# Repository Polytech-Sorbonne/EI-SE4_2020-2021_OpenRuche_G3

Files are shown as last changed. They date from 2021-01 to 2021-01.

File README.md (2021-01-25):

# Projet Open Ruche 2020-2021

Ce projet avait pour but de concevoir une ruche connectée afin de vérifier la production de miel des abeilles ainsi que leur bonne santé. Il a été conduit de     
septembre 2020 jusque janvier 2021 par quatre élèves de Polytech Sorbonne EISE4 : Clément Leboulenger, Edouard Matheu, Julie Rago et Clément Roger.

Notre ruche connectée comportait un PCB utilisant un microcontrôleur L432KC et implémentait différents capteurs et fonctionnalités:

  - Un capteur mesurant la température et l'humidité extérieures (le DHT22)
  - Un capteur mesurant la température intérieure (le DS18B20)
  - Une station météo mesurant la vitesse du vent (la LEXCA007)
  - Un capteur de poids (le HX711)
  - Un boitier étanche et facile d'utilisation comportant un bouton ON / OFF et une LED
  - Une mesure du pourcentage de la batterie
  - Une transmission des données sur une plateforme de visualisation des données (Ubidots)
  - Une application d'alertes envoyant des mails au client en cas de problème
 
Tous les codes sources ont été écrits sur mbed et sont disponibles dans le dossier [src](src) 

## Etape 1 : Prototype sur LABDEC

Afin de reproduire le prototype sur labdec il suffit de reproduire le branchement suivant puis de charger le code sur le microcontrôleur avec MBED.

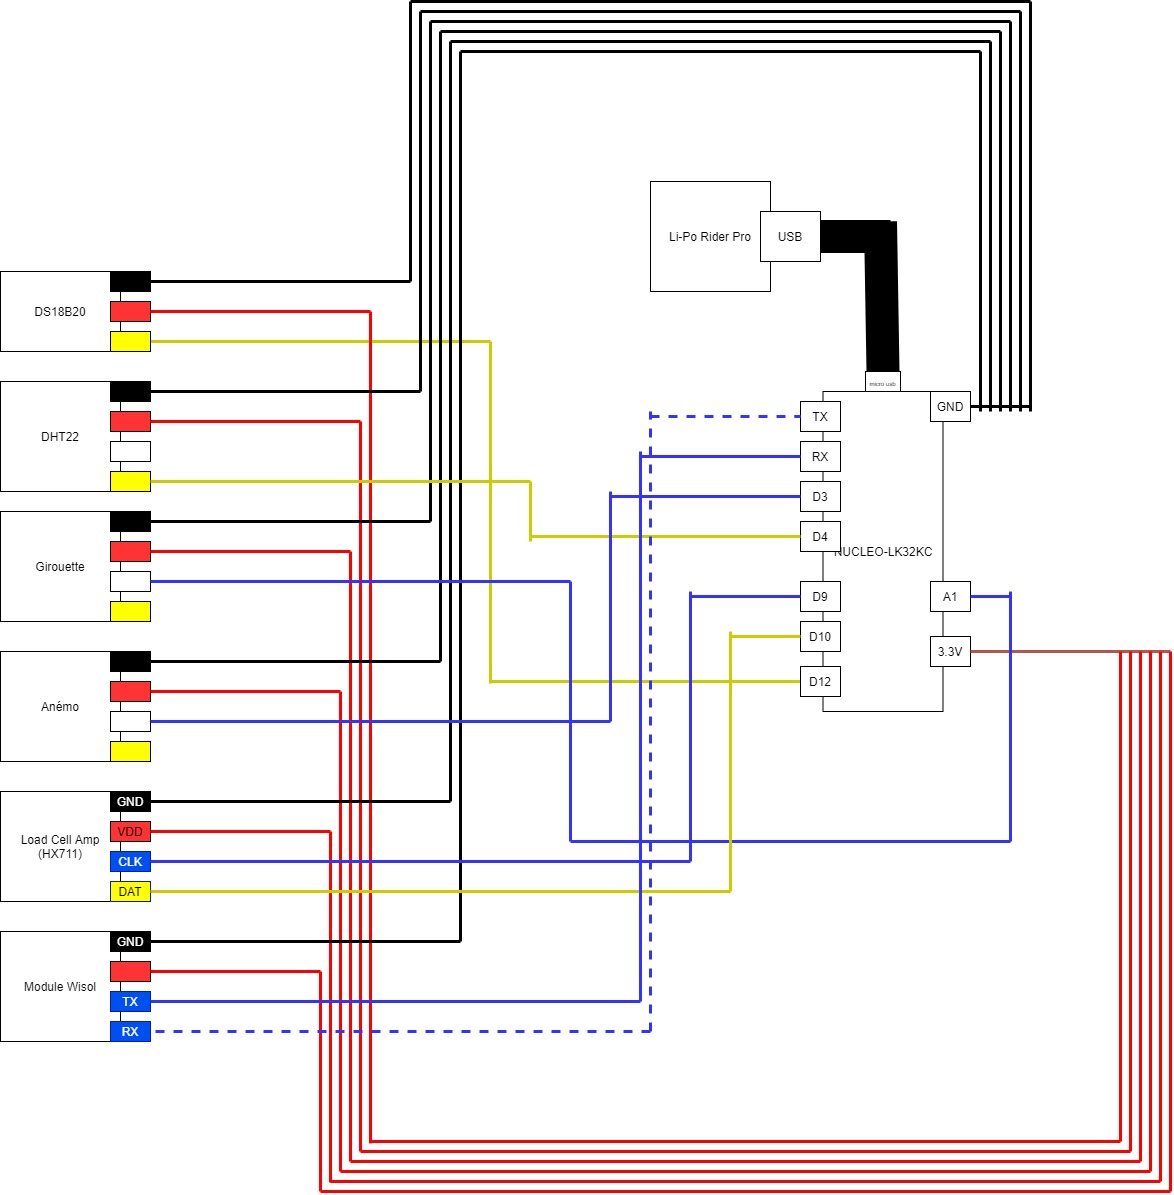
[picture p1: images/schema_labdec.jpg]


## Etape 2 : Visualisation des données

Afin de vérifier le bon fonctionnement du prototype il faut pouvoir visualiser les données reçues. Une première solution est d'afficher ces dernières en série sur le terminal, néanmoins ceci n'est pas viable à long terme.

Nous avons utilisé la plateforme Ubidots qui permet une grande diversité de widgets. Pour cela il faut d'abord programmer le callback. Pour cela, nous vous invitons à suivre ce [tutoriel](https://www.google.com/url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).

Ensuite il suffira de programmer le callback comme suivant :

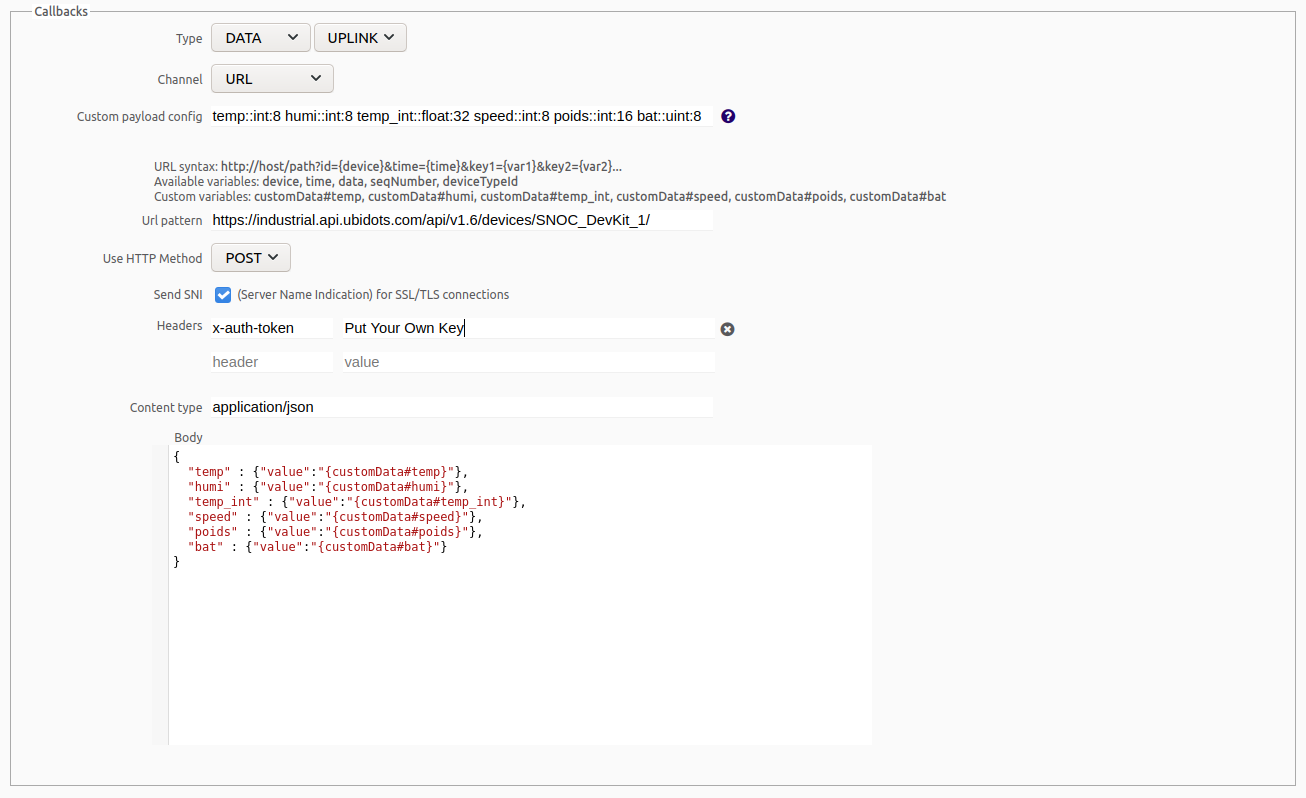
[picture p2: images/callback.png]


## Etape 3 : Création du PCB

Afin d'obtenir un produit final robuste et résistant il convient de concevoir un PCB (ou circuit imprimé).

Le nôtre a été réalisé sur Kicad, tous les fichiers de conception étant présents [ici](kicad_pcb)

## Etape 4 : Branchements sur PCB

Il vous faut maintenant souder les composants (connecteurs Grove, headers ...) et brancher les différents capteurs sur le PCB comme suit :

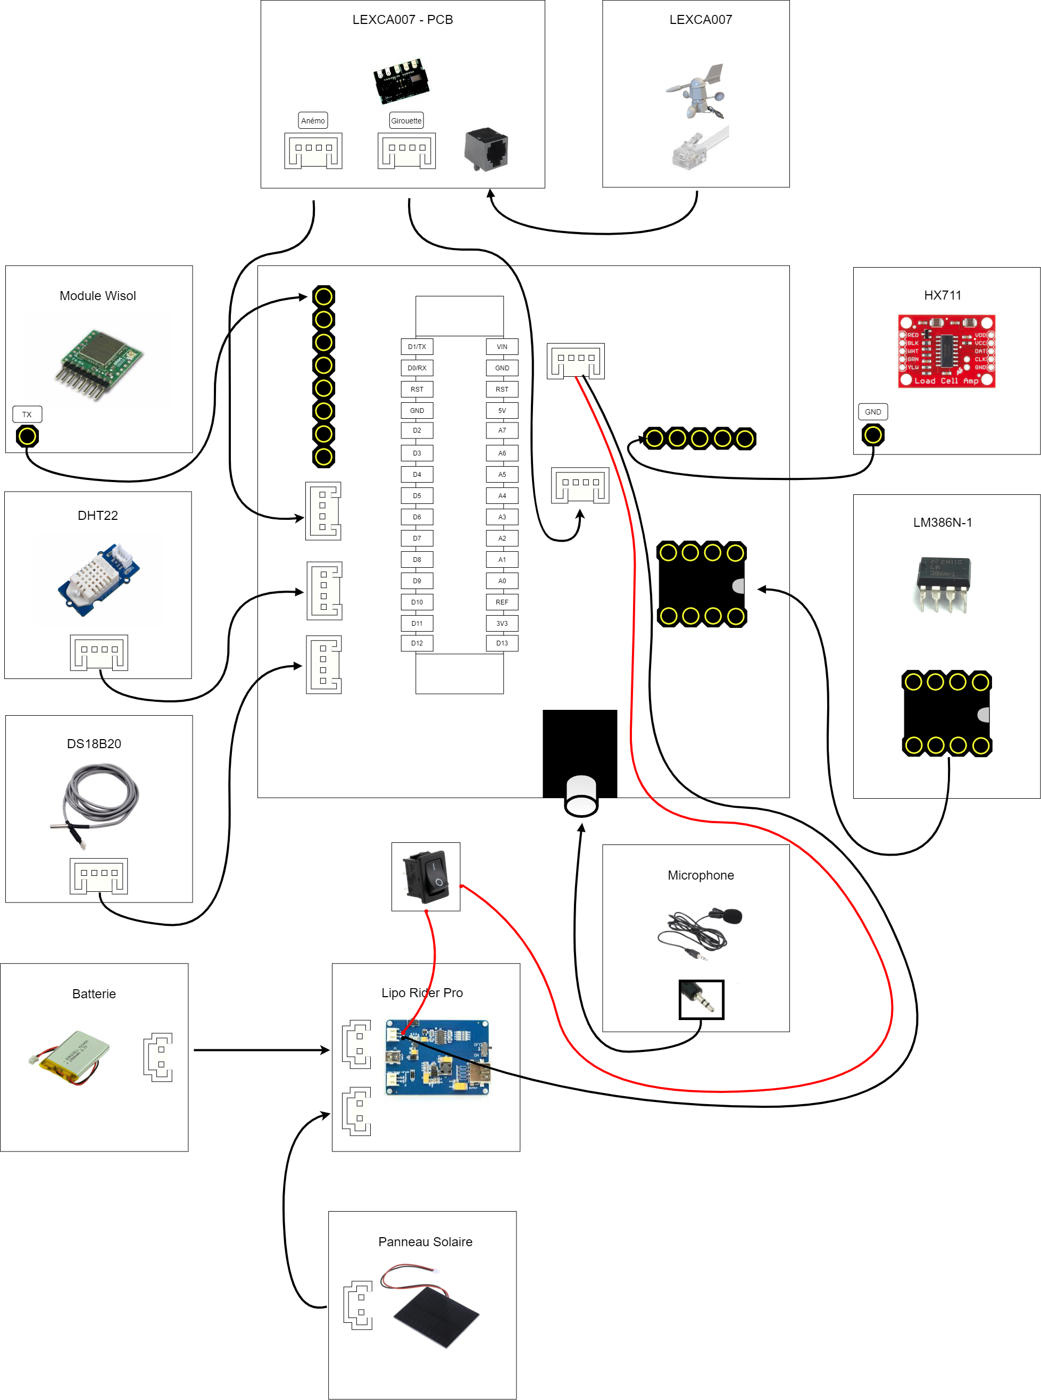
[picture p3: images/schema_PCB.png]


**Après** avoir chargé le code sur le microcontrôleur (car une fois fait vous ne pourrez plus charger de code dessus) il vous faudra néanmoins déssouder des solder bridges sur le microcontrôleur afin de réduire la consommation du système et permettre l'accès du microcontrôleur à certaines pins. 

Les solder bridges à retirer sont les suivants :

  - SB9
  - SB14
  - SB16
  - SB18
  
Les solder bridges sont inscrits directement sur le microcontrôleur ou vous pouvez trouver l'emplacement de ces derniers sur l'image suivante

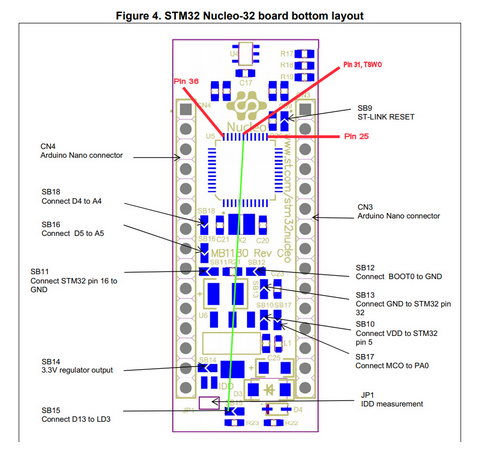
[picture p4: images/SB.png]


Après avoir suivi ces étapes, il ne vous reste plus qu'à mettre le tout dans une boîte étanche.

Vous pouvez également allonger les câbles avec des gaines, isoler le tout avec de la colle à chaud et faire des plateformes pour certains capteurs pour qu'ils tiennent mieux sur la ruche.

Pour tout détail sur l'utilisation, veuillez vous référer à la [notice d'utilisation](documentation_technique/Notice.pdf)

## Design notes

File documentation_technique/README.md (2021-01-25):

# Documentation technique

[stm32l432kc.pdf](stm32l432kc.pdf) contient le datasheet de la nucleo L432KC.

[dm00231744-stm32-nucleo32-boards-mb1180-stmicroelectronics.pdf](dm00231744-stm32-nucleo32-boards-mb1180-stmicroelectronics.pdf) contient le user manual de la nucleo, notamment un schéma électronique de la carte, la position des solder bridges et leur utilité.

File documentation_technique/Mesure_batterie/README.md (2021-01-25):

# Mesure de la batterie

Il convient de savoir que la courbe de la décharge d'une batterie n'est pas linéaire mais a plutôt cette forme (trouvable sur la [datasheet](datasheet.pdf) )

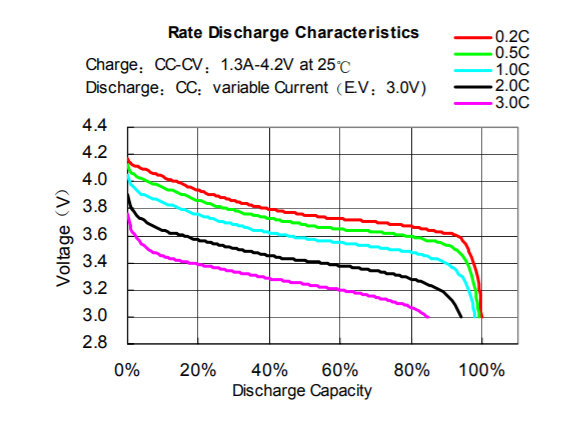
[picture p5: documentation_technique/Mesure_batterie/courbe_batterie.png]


Il est possible d'obtenir la tension d'entrée grâce au micronctôleur en multipliant le résultat de la fonction _read()_ par la tension d'alimentation du microcontrôleur (ici _3.3 V_) et en divisant par 0.6 dû au pont diviseur de tension. Il ne nous reste plus qu'à trouver l'équation de la courbe en fonction de la tension d'entrée afin de pouvoir obtenir la mesure du pourcentage de la batterie.

Pour cela, nous traçons tout d'abord sur Excel la courbe de décharge de la batterie en inversant les axes, le fichier étant disponible [ici](courbe_charge.xlsx). Nous aurons donc le pourcentage de la batterie en fonction de la tension d'entrée comme sur l'image ci dessous.

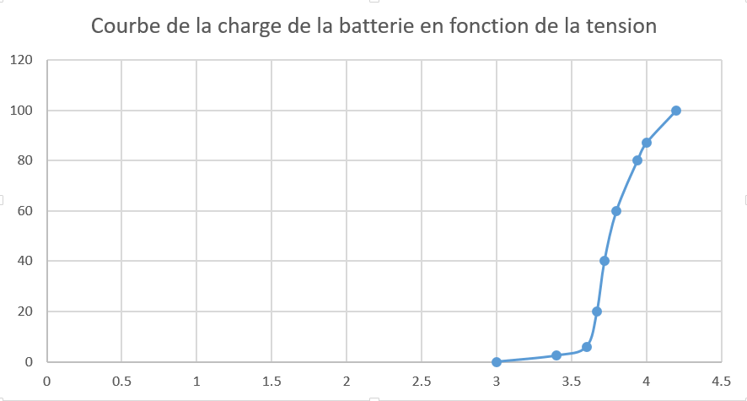
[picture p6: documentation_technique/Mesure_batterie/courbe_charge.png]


Il ne nous reste plus qu'à faire un clique droit sur la courbe et ajouter une courbe de tendance. Excel propose de nombreuses possibilités de modélisations de courbes de tendances (linéaires, polynomiales, logarithmiques ...). Il convient de les tester une à une jusqu'à obtenir celle se confondant le plus possible avec la courbe voulue, puis d'afficher son équation.

La courbe que nous avons étant particulière, nous la divisons en trois tronçons : un tronçon linéaire entre 4 V et 4.2 puis deux tronçons polynomiaux entre 3.6 V et 4 V puis 3 V et 3.6 V. Excel nous fournit donc les équations suivantes qui seront implémentées dans le code.



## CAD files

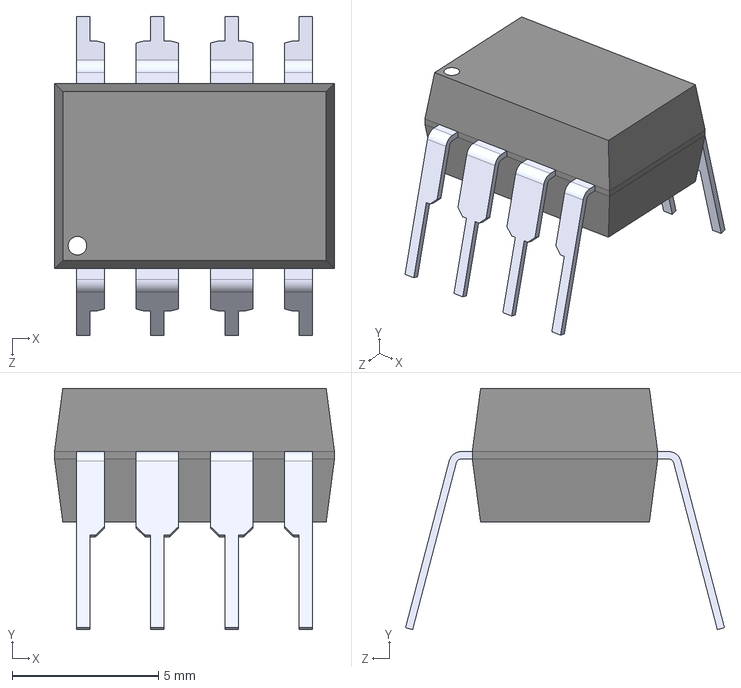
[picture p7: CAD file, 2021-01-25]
kicad_pcb/librairie/LM386N-4_NOPB/LM386N-4_NOPB.step
9.59 x 8.25 x 10.9 mm

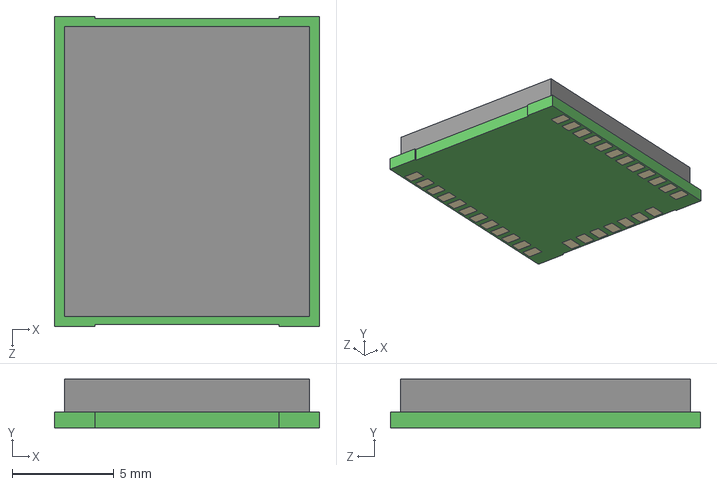
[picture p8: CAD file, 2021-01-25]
kicad_pcb/librairie/WSSFM10R1AT/WSSFM10R1AT.step
13.0 x 2.38 x 15.2 mm

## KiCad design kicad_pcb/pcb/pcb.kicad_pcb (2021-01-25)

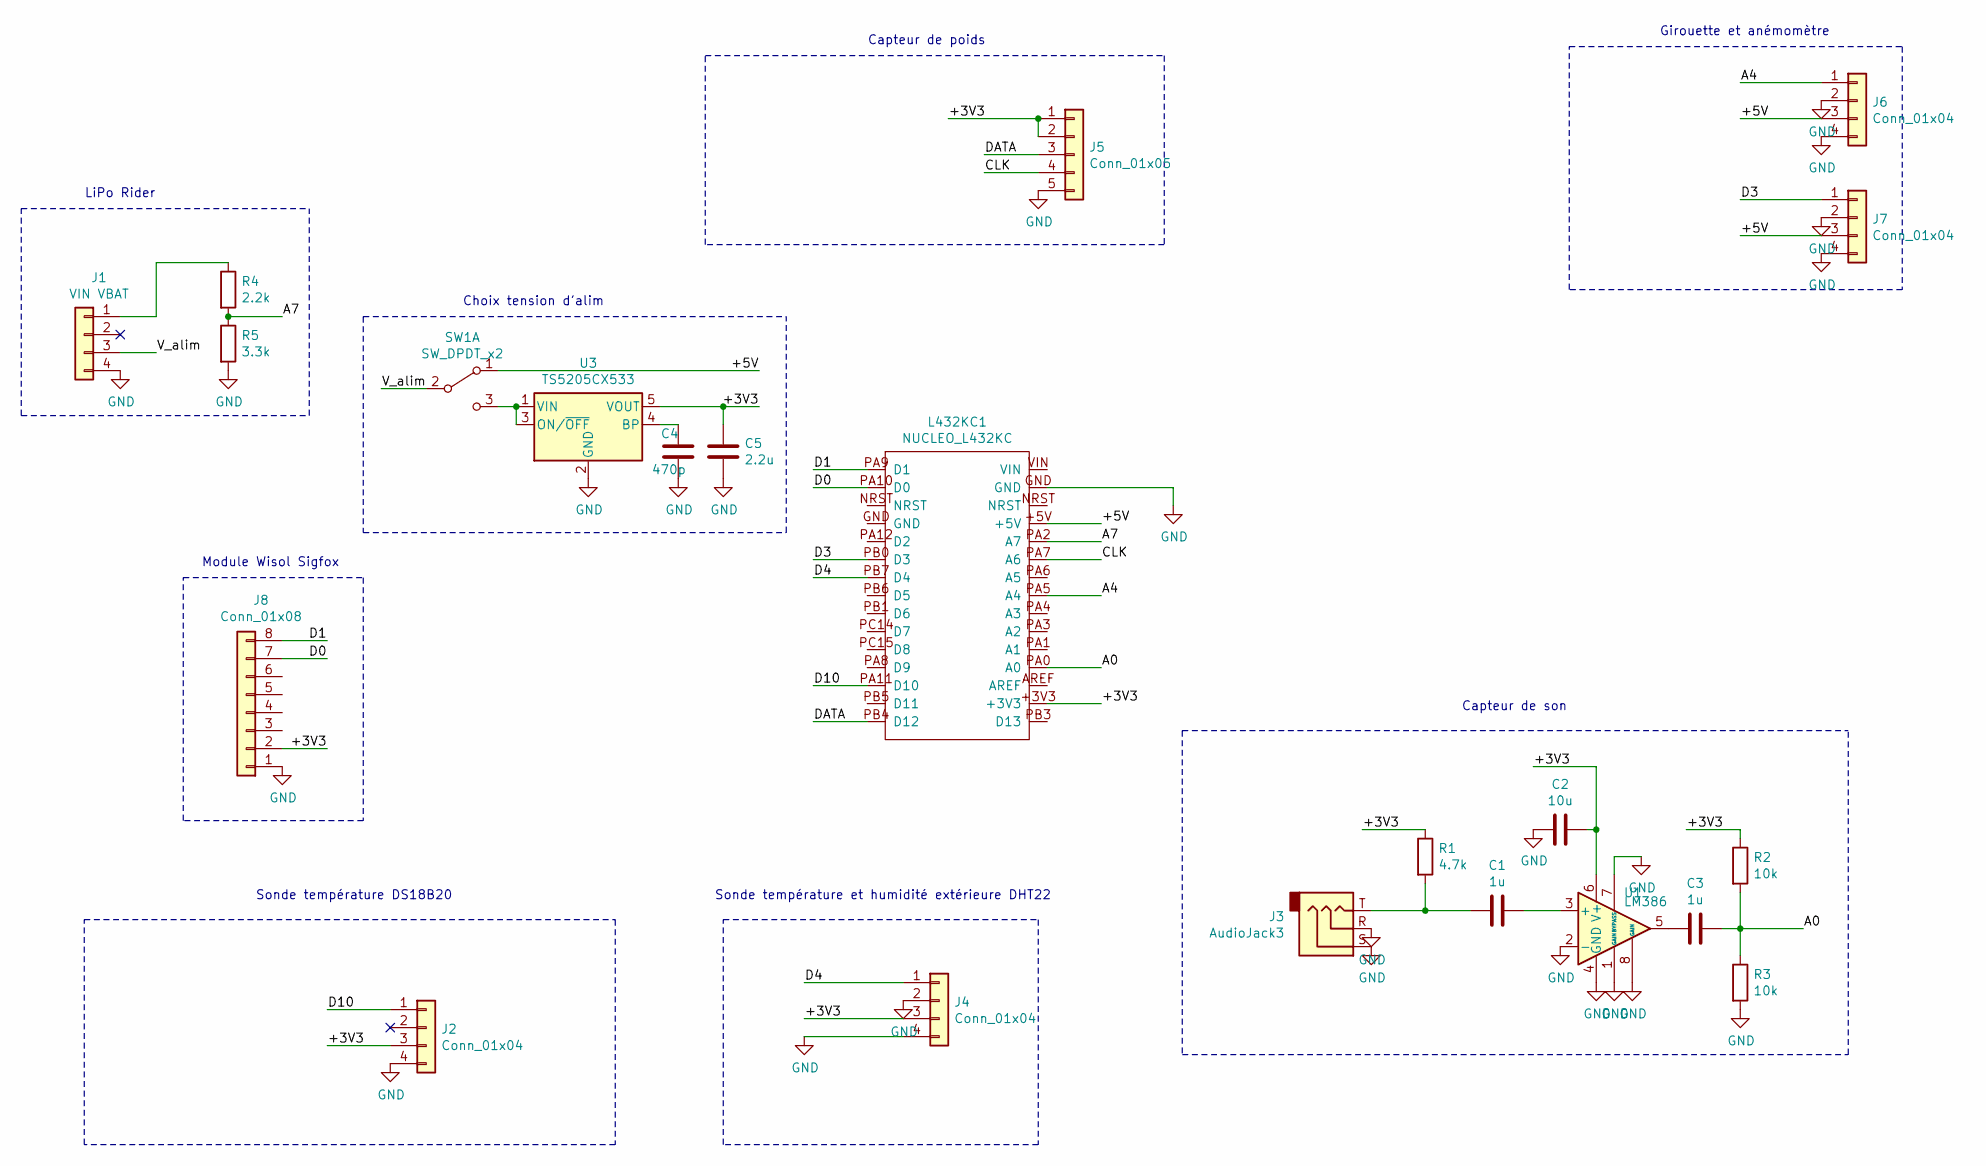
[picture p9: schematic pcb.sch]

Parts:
C1, C3: 1u; CP_Radial_D6.3mm_P2.50mm
C2: 10u; CP_Radial_D5.0mm_P2.00mm
C4: 470p; C_0805_2012Metric_Pad1.18x1.45mm_HandSolder
C5: 2.2u; C_0805_2012Metric_Pad1.18x1.45mm_HandSolder
J1: VIN VBAT; PinHeader_1x04_P2.00mm_Vertical
J2, J4, J6, J7: Conn_01x04; PinHeader_1x04_P2.00mm_Vertical
J3: AudioJack3; Jack_3.5mm_Ledino_KB3SPRS_Horizontal
J5: Conn_01x05; PinHeader_1x05_P2.54mm_Vertical
J8: Conn_01x08; PinHeader_1x08_P2.54mm_Vertical
L432KC1: NUCLEO_L432KC; MODULE_NUCLEO-L432KC
R1: 4.7k; R_Axial_DIN0207_L6.3mm_D2.5mm_P10.16mm_Horizontal
R2, R3: 10k; R_Axial_DIN0207_L6.3mm_D2.5mm_P10.16mm_Horizontal
R4: 2.2k; R_Axial_DIN0207_L6.3mm_D2.5mm_P10.16mm_Horizontal
R5: 3.3k; R_Axial_DIN0207_L6.3mm_D2.5mm_P10.16mm_Horizontal
SW1: SW_DPDT_x2; PinHeader_2x02_P2.54mm_Vertical
U1: LM386; DIP794W45P254L959H508Q8
U3: TS5205CX533; SOT-23-5

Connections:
/+3V3: C2.1, C5.1, J2.3, J4.3, J5.1, J5.2, J8.2, L432KC1.+3V3, R1.1, R2.1, U1.6 (V+), U3.5 (VOUT)
/+5V: J6.3, J7.3, L432KC1.+5V, SW1.1 (A)
/A0: C3.1, L432KC1.PA0 (A0), R2.2, R3.1
/A4: J6.1, L432KC1.PA5 (A4)
/A7: L432KC1.PA2 (A7), R4.2, R5.1
/CLK: J5.4, L432KC1.PA7 (A6)
/D0: J8.7, L432KC1.PA10 (D0)
/D1: J8.8, L432KC1.PA9 (D1)
/D3: J7.1, L432KC1.PB0 (D3)
/D4: J4.1, L432KC1.PB7 (D4)
/D10: J2.1, L432KC1.PA11 (D10)
/DATA: J5.3, L432KC1.PB4 (D12)
/V_alim: J1.3, SW1.2 (B)
GND: C2.2, C4.2, C5.2, J1.4, J2.4, J3.R, J3.S, J4.2, J4.4, J5.5, J6.2, J6.4, J7.2, J7.4, J8.1, L432KC1.GND, R3.2, R5.2, U1.1 (GAIN), U1.2 (-), U1.4 (GND), U1.7 (BYPASS), U1.8 (GAIN), U3.2 (GND)
unnamed: C1.1, U1.3 (+)
unnamed: C1.2, J3.T, R1.2
unnamed: C3.2, U1.5
unnamed: C4.1, U3.4 (BP)
unnamed: J1.1, R4.1
unnamed: SW1.3 (C), U3.1 (VIN), U3.3 (ON/~OFF~)

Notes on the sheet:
Sonde température DS18B20
Sonde température et humidité extérieure DHT22
Capteur de son
Girouette et anémomètre
LiPo Rider
Capteur de poids
Module Wisol Sigfox
Choix tension d'alim

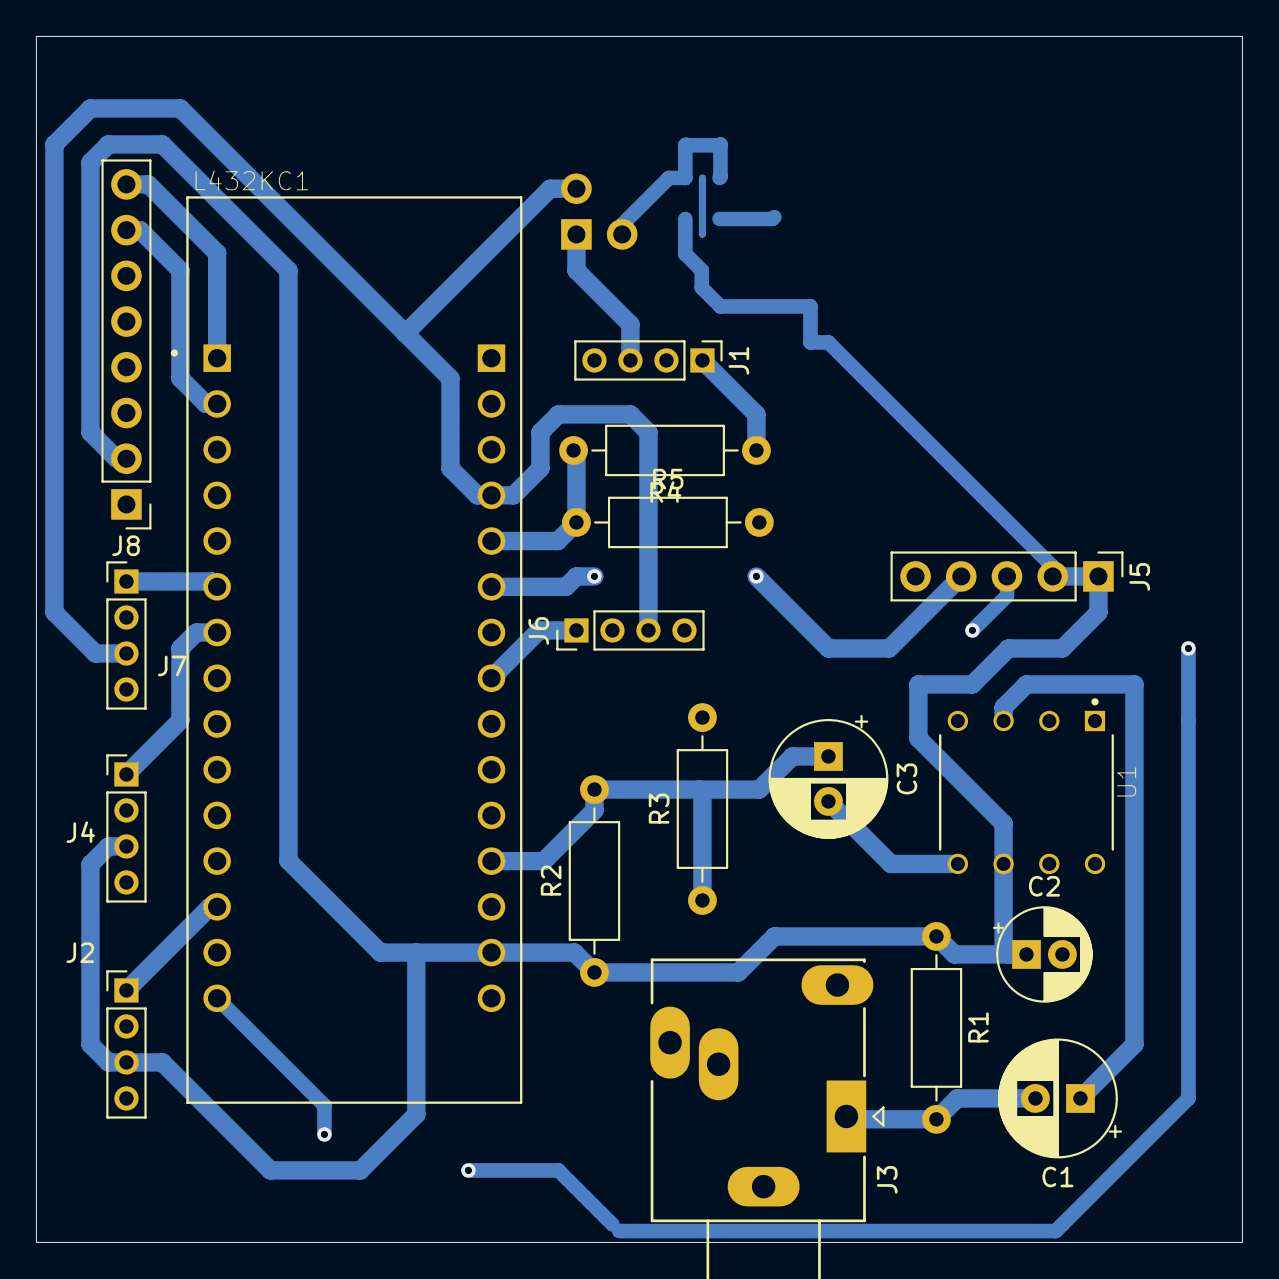
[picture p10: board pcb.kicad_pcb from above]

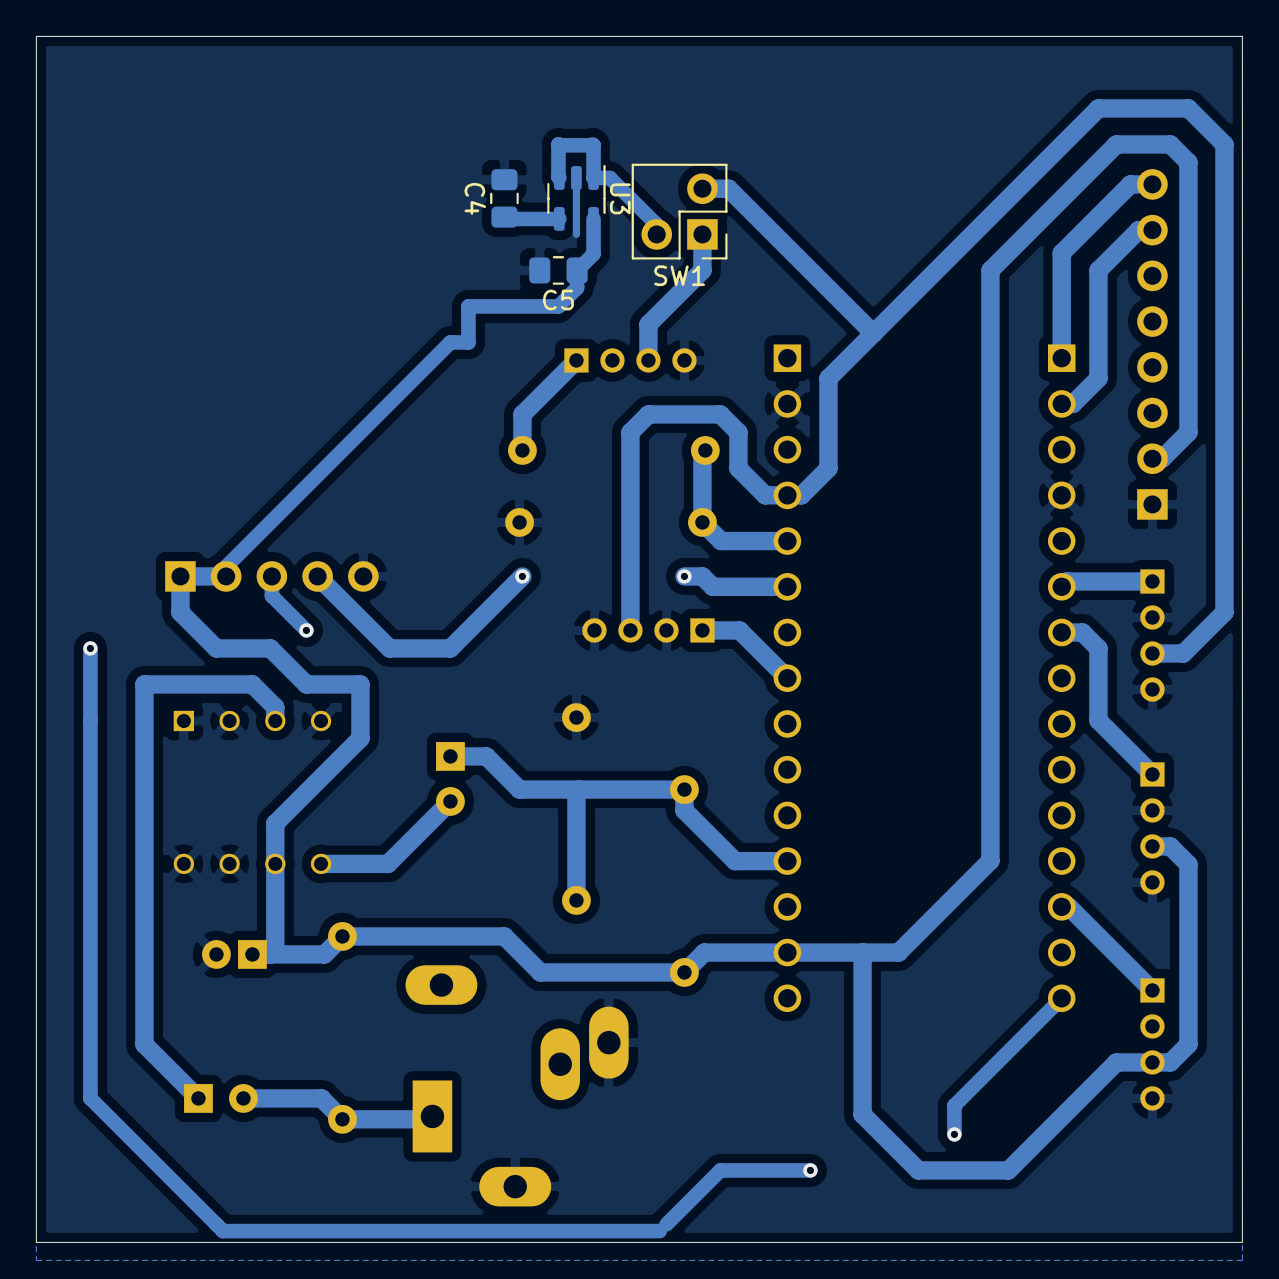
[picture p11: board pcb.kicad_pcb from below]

Board: 2 copper layers, 67.0 x 67.0 mm, 22 parts (4 on the bottom side), 20 nets.

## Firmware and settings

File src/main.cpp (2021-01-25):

#include "mbed.h"
#include "DHT.h"
#include "DS1820.h"
#include "mbed.h"
#include "mesures_vent.h"
#include "Hx711.h"
#include "mesure_tension.h"

#define SECOND 1000
#define MINUTE 60000

#define BAUD_RATE 9600

#define OFFSET -105536
#define SCALE 0.971115

#define V_entree 5 //Changer si en 5V

Serial Sigfox(D1, D0);
Serial serie(USBTX, USBRX);
DS1820  ds1820(D10);
DHT sensor(D4,22);
Hx711 capteur_poids(A6, D12);
AnalogIn batterie(A4);

InterruptIn button(D9);
DigitalOut led(D2);

bool button_interrupt = false;

union hex_float_t {
    float f;
    uint32_t u;
}; 


void led_init_system(){
    
        led = 1;
        wait_us(3e6);
        led = 0;
}

void flip();

void sleep_handler()
{
    //printf("WAKE UP\r\n");
}

int main() {
    
    //Interruption et commutation à la fonction
    button.mode(PullUp);
    button.fall(&flip);

    button.disable_irq();
    led_init_system();
    
    Sigfox.baud(BAUD_RATE);
    
    int8_t temp;
    uint8_t humi;
    eScale CELSIUS;

    float temp_int;
    hex_float_t temp_int_sent;
    int err;
    
    double *_frac;
    int message_counter = 0;

    int8_t direction;
    int8_t speed;
    
    float poids_temp;
    hex_float_t poids;
    
    int8_t pourcentage_bat;
    
    if(!ds1820.begin())
        serie.printf("La sonde n'a pas été trouvée\r\n");
        
    capteur_poids.power_up();
    capteur_poids.set_offset(0);
    capteur_poids.set_scale(1.0);
    serie.printf("Régler OFFSET à %d:\r\n", (int)(capteur_poids.read()));
        
    capteur_poids.set_offset(OFFSET);
    capteur_poids.set_scale(SCALE);
    
    ThisThread::sleep_for(1000); // Bootup
    
    while(1) {
        
        capteur_poids.power_up();
        
        while(sensor.readData()){
            printf("Erreur lors de la lecture du DHT22\r\n");
            wait_us(500000);
        }
        humi = sensor.ReadHumidity();
        temp = sensor.ReadTemperature(CELSIUS);
        direction = Send_direction();
        speed = Send_speed();
        pourcentage_bat = pourcentage_batterie(batterie.read());
        
        ds1820.startConversion();    // Début la séquence de conversion
        ThisThread::sleep_for(1000); // Temporisation pour laisser le temps au DS18B20 de finir la conversion
        err = ds1820.read(temp_int);   // Lecture de la donnée convertie par le DS18B20 et contrôle de redondance cyclique
        temp_int_sent.f = temp_int;
        serie.printf("Message %d:\r\n", message_counter++);
        
       /* switch(err) {
            case 0:    // Pas d'erreur : temperature contient la valeur de température mesurée
                //serie.printf("Température intérieure : %3.1f degrés\r\n", temp_int);
                break;
            case 1:    // Le DS18B20 n'est pas détecté : temperature n'est pas actualisé
                //serie.printf("DS18B20 non détecté\r\n");
                break;
            case 2:    // Erreur dans le contrôle de redondance cyclique : temperature n'est pas actualisé
                //serie.printf("Erreur dans le contrôle de redondance cyclique\r\n");
                break;
        }*/
         
        //serie.printf("Température extérieure : %2d degrés\r\nHumidité : %03d pourcents\r\n", temp, humi);
        //serie.printf("Vent : Direction = %d | Vitesse = %d km/h\r\n",direction,speed);
        poids_temp = (-0.0001)*capteur_poids.read();
        poids.f = poids_temp;
        //serie.printf("Poids float : %f kg\r\n",poids.f);
        //serie.printf("Poids hexa : %d kg\r\n",poids.u);
        //serie.printf("Pourcentage batterie : %d\r\n", pourcentage_bat);
        
        Sigfox.printf("AT$SF=%02x%02x%08x%02x%04x%02x\r\n", (int8_t)temp, (int8_t)humi, temp_int_sent.u, (int8_t)speed, (int16_t)(poids.f*10.0), pourcentage_bat);
        serie.printf("temp:[%02x] humi:[%02x] temp_int:[%08x] speed:[%02x] poids:[%04x] bat:[%02x]\r\n", (int8_t)temp, (int8_t)humi, temp_int_sent.u, (int8_t)speed, (int16_t)(poids.f*10.0), (int8_t)pourcentage_bat);
        
        capteur_poids.power_down();
        //ThisThread::sleep_for(SECOND*30);
        //ThisThread::sleep_for(MINUTE/15);
        //sleep_interrupt.attach_us(&sleep_handler, 30*SECOND);
        //button.enable_irq();
        ThisThread::flags_wait_any_for(button_interrupt, 15*MINUTE, false);
        //button.disable_irq();
        //sleep_interrupt.detach();
        
    }
}

void flip(){
    /*
    button.disable_irq();
    wait_us(50000);
    button.enable_irq();
    */
    //Témoin LED
    /*for(int i = 0; i < 2; i++){
        led = 1;
        wait_us(20000);
        led = 0;
        wait_us(10000);
    }*/
    
    button_interrupt = true;
    //printf("BUTTON\r\n");
        
}
